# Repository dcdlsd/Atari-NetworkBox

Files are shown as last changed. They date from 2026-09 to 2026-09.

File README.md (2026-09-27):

# The Atari NetworkBox

> Français d'abord — English version below.

Une passerelle réseau autonome pour Atari ST : le port modem RS-232 est
converti par un MAX3232 vers un Raspberry Pi Pico 2 W. L'Atari utilise STinG
en SLIP à **19 200 bauds, 8N1** et peut accéder au réseau par Wi-Fi ou RJ45.

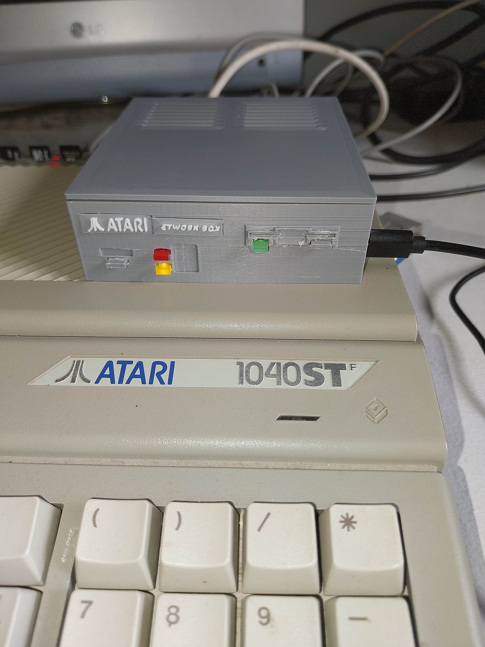
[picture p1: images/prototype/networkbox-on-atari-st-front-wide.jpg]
Prototype


## Fonctions validées

- navigation HTTP avec HighWire ;
- FTP avec Litchi ;
- DNS, ping et TCP/IP via STinG / SLIP ;
- firmware Wi-Fi seul, RJ45/W5500 seul, ou Wi-Fi + RJ45 unifié ;
- bouton de sélection et LEDs facultatives pour le firmware unifié.

## Vitesse série — important

Les **trois firmwares UF2 fournis** (Wi-Fi seul, RJ45 seul et unifié) sont
compilés avec une vitesse série **fixe de 19 200 bauds, 8N1**. Le port série
utilisé par STinG sur l'Atari doit être réglé à la même vitesse.

Ce réglage a été validé sur notre Atari STF. Il concerne la liaison série
Atari–Pico, pas la vitesse du Wi-Fi ou de l'Ethernet, et ne constitue pas une
limite matérielle du Pico.

Brancher la NetworkBox sur un autre modèle d'Atari ne change pas automatiquement
cette vitesse. Pour utiliser un port série plus rapide, il faudrait adapter
et recompiler le firmware, puis valider le fonctionnement sur la machine et
le port concernés. **Les vitesses supérieures ne sont pas validées dans cette
version.**

## Démarrage rapide

1. Imprimez le boîtier de `case_stl/` si souhaité, puis suivez le
   [montage en photos](docs/ASSEMBLY.md) pour placer le Pico et les modules.
2. Réalisez le câblage décrit dans [WIRING.md](WIRING.md).
3. Flashez **un seul** fichier `.uf2` depuis `firmware/` :
   - `...WIFI_only_v1.0.5.uf2` : Wi-Fi uniquement ;
   - `...W5500_RJ45_only_v1.0.4.uf2` : RJ45 uniquement ;
   - `...WIFI_and_RJ45_v0.6.5.uf2` : version unifiée recommandée.
4. Installez STinG sur l'Atari puis utilisez les exemples de
   `atari_config_examples/`. Consultez `docs/STING_SETUP.md`.
5. Pour le Wi-Fi, utilisez le portail de configuration décrit dans
   `docs/WIFI_SETUP.md`.

Les fichiers `.uf2` s'installent en maintenant **BOOTSEL** enfoncé pendant le
branchement USB du Pico, puis en déposant le fichier sur le disque USB du Pico.

## Organisation

- `firmware/` : firmwares compilés prêts à flasher ;
- `source/` : code source des trois variantes ;
- `case_stl/` : boîtier imprimable ;
- `atari_config_examples/` : exemples STinG et Litchi ;
- `images/` : prototype, schéma et captures Atari ;
- `docs/` : installation et ressources.

## État du prototype

Projet matériel open source réalisé comme prototype. Les modules, le boîtier
et les connecteurs peuvent varier : vérifiez toujours les sérigraphies de votre
MAX3232 et W5500 avant alimentation. Voir [WIRING.md](WIRING.md).

## Licence

Le code source et les firmwares sont sous [licence MIT](LICENSE). Le boîtier,
le câblage, les images et la documentation sont sous [CC BY
4.0](LICENSES/CC-BY-4.0.md). La réutilisation et la vente sont autorisées, à
condition de conserver le crédit de Denis Costils et les notices de licence.
Les composants tiers conservent leurs propres licences : voir
[THIRD_PARTY_NOTICES.md](THIRD_PARTY_NOTICES.md).

---

# English

The Atari NetworkBox is a standalone network gateway for the Atari ST. A
MAX3232 converts the RS-232 modem port to a Raspberry Pi Pico 2 W UART. The
Atari runs STinG over SLIP at **19,200 baud, 8N1**, with Wi-Fi or Ethernet
connectivity.

Validated features: HTTP with HighWire, FTP with Litchi, DNS, ping and TCP/IP.
Three ready-to-flash firmwares are supplied: Wi-Fi only, W5500 Ethernet only,
and a combined Wi-Fi + Ethernet version.

## Serial speed — important

All **three supplied UF2 firmwares** (Wi-Fi only, Ethernet only and combined)
are compiled for a **fixed serial speed of 19,200 baud, 8N1**. The Atari serial
port used by STinG must be configured to match.

This setting has been tested on our Atari STF. It applies to the Atari–Pico
serial link, not to Wi-Fi or Ethernet speed, and is not a hardware limitation
of the Pico.

Connecting the NetworkBox to another Atari model does not automatically change
the serial speed. Using a faster serial port would require adapting and
recompiling the firmware, then testing it on the relevant machine and port.
**Higher serial speeds have not been validated in this version.**

## Getting started

See the [photo assembly guide](docs/ASSEMBLY.md) for the Pico and module
positions, [WIRING.md](WIRING.md) for hardware connections,
`docs/STING_SETUP.md` for Atari configuration and `docs/WIFI_SETUP.md` for
Wi-Fi setup.

## License

Source code and firmware are [MIT licensed](LICENSE). Case files, wiring,
images and documentation are licensed under [CC BY 4.0](LICENSES/CC-BY-4.0.md).
Commercial reuse is allowed with credit and preservation of license notices.

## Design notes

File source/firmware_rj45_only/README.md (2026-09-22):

# NetworkBox SLIP / W5500 test

Separate Pico 2 W firmware for testing the Atari SLIP link through the W5500.
The validated Wi-Fi firmware remains in `../networkbox_slip_wifi` and is not
modified by this project.

## Wiring

- Atari RS-232 through MAX3232: Pico GP0 TX, GP1 RX, 19200 baud, 8N1.
- W5500 SPI0: MISO GP16, CS/SS GP17, SCK GP18, MOSI GP19, RESET GP20.
- Connect Ethernet to the same LAN/router that provides DHCP before powering
  the Pico. The firmware waits for physical link and then requests DHCP.

## Test

1. Flash `releases/networkbox_slip_w5500_ping_test.uf2` to the Pico 2 W.
2. Open the Pico USB serial monitor at 115200 baud.
3. Wait for `W5500 Ethernet link up`, then for `NetworkBox active - W5500 IP ...`.
4. Start STinG on the Atari and run the existing `PING.PRG` against the router
   (usually `192.168.1.254`) first. Once that works, try the PC IP.
5. Keep the Wi-Fi UF2 as the rollback option; this W5500 image has not yet been
   validated on the physical Network Box.

## Build

Open this directory as a separate Pico project in VS Code and build
`networkbox_slip_w5500`. It uses the local Pico SDK 2.3.1 and the WIZnet
ioLibrary_Driver plus WIZnet's lwIP MACRAW adapter. The adapter's SPI pins are
the same as the wiring listed above.

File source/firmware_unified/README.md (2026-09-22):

# NetworkBox unified test

This is an independent experimental project. The two validated projects
`networkbox_slip_wifi_setup` and `networkbox_slip_w5500` are not modified.

## Behaviour of v0.1

- If the RJ45 cable is connected when Pico starts, the W5500 is selected.
- Otherwise, Pico connects with the saved Wi-Fi configuration.
- If Wi-Fi credentials are missing or invalid, the existing setup page starts:
  `NetworkBox-Setup`, password `networkbox`, page `http://192.168.4.1`.
- There is deliberately no button or LED support in this first unified test.

The temporary access point is WPA2 protected. The saved password is not shown
by the page or in USB logs.

## Hardware test

1. Keep the validated Wi-Fi and W5500 UF2 files as backups.
2. Copy `releases/networkbox_unified_v0.1_boot_rj45_wifi_fallback.uf2` to Pico 2 W
   in BOOTSEL mode.
3. First test with RJ45 connected: the monitor must show `W5500 set as default`
   and then `NetworkBox active - W5500 OK`.
4. Validate Atari ping, then HighWire or FTP.
5. Reflash only if needed, unplug RJ45, and boot again. The monitor must show
   `Connecting to saved Wi-Fi...` followed by `NetworkBox active - Wi-Fi OK`.
6. Validate Atari ping, then HighWire or FTP again.

## Current scope

This test deliberately has no button, LEDs, live cable failover, or factory
reset. Those belong in the next unified firmware step.

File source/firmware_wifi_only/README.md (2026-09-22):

# Atari NetworkBox — firmware Wi-Fi seul

Firmware pour Raspberry Pi Pico 2 W. Il relie un Atari ST configure avec
STinG/SLIP a un reseau Wi-Fi via le montage RS-232 et MAX3232.

Cette edition est independante du W5500 : aucun module Ethernet, bouton ou
LED n'est requis.

## Premier demarrage

1. Flasher le fichier `.uf2` sur le Pico 2 W.
2. Depuis un telephone ou un PC, rejoindre le Wi-Fi `NetworkBox-Setup` avec le
   mot de passe `networkbox`.
3. Ouvrir `http://192.168.4.1`.
4. Choisir le Wi-Fi dans la liste (ou saisir un SSID masque), entrer le mot de
   passe puis enregistrer.
5. Le Pico redemarre et memorise les identifiants dans sa propre memoire flash.

Les identifiants ne sont pas inclus dans les sources ni dans le fichier UF2.

## Changer de reseau plus tard

Le bouton est facultatif. S'il est installe entre **GP4** et **GND**, un appui
maintenu trois secondes pendant que le Wi-Fi est connecte reouvre le portail
de configuration. Sans bouton, le portail s'ouvre automatiquement si le
reseau memorise ne peut plus etre rejoint.

## Atari ST

Configurer STinG en SLIP sur le port modem, a **19 200 bauds, 8N1** :

- Atari : `192.168.7.2`
- passerelle : `192.168.7.1`
- masque : `255.255.255.0`

La configuration a ete validee avec ping, DNS, HTTP/HighWire et FTP/Litchi.

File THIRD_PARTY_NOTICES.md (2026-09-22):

# Third-party notices

The project source tree contains third-party components. Their original
license notices are retained beside the relevant source files and take
precedence for those components.

In particular, the WIZnet ioLibrary Driver is distributed with its original
license text in each firmware source folder as `LICENSE-ioLibrary.txt`.

Raspberry Pi Pico SDK and lwIP components are obtained through the normal Pico
SDK build process and remain under their respective upstream licenses.

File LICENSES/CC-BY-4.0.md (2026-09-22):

# CC BY 4.0 — hardware, case and documentation

Copyright (c) 2026 Denis Costils

Unless a file says otherwise, the following parts of The Atari NetworkBox are
licensed under the [Creative Commons Attribution 4.0 International
license](https://creativecommons.org/licenses/by/4.0/):

- `case_stl/`
- `images/`
- `WIRING.md`
- `docs/`
- `atari_config_examples/`

You may share and adapt these materials for any purpose, including commercial
use, provided that you give appropriate credit to **Denis Costils**, link to
the license, and state whether changes were made.

The complete legal text is available at
https://creativecommons.org/licenses/by/4.0/legalcode.

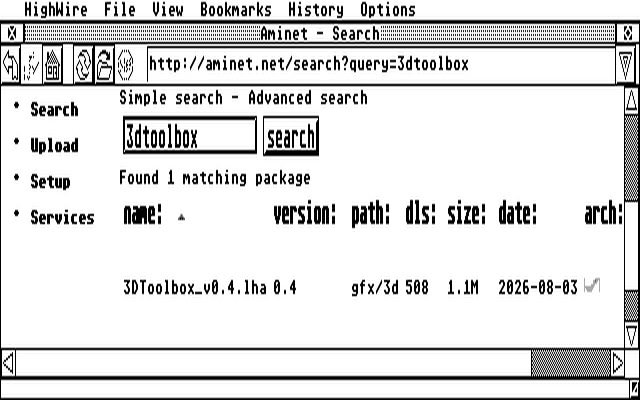
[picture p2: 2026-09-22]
images/atari-screenshots/highwire-aminet-search.jpg

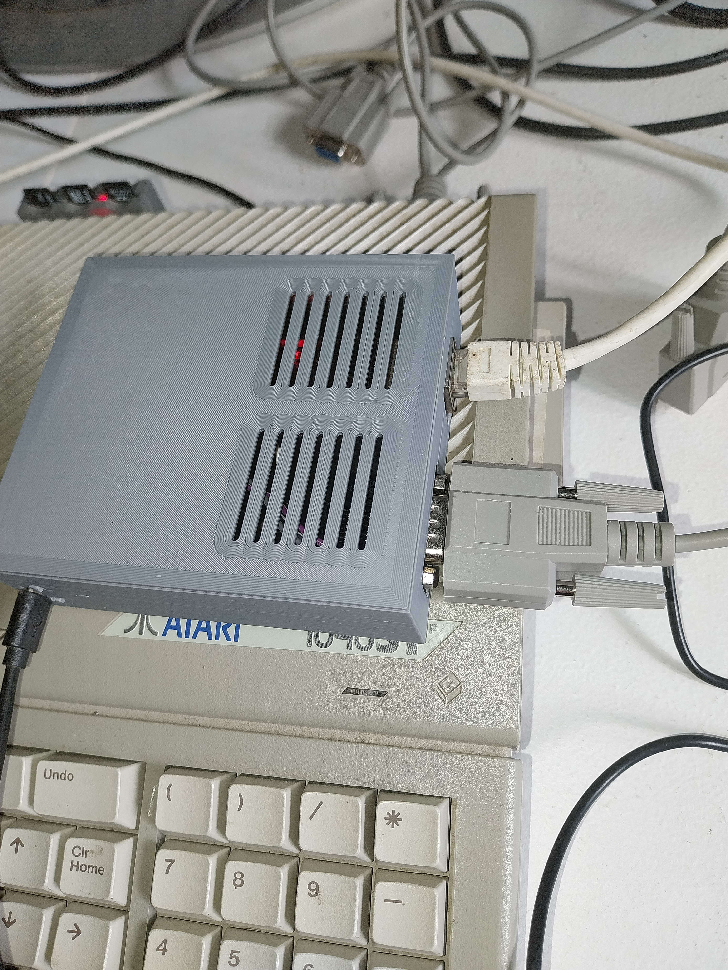
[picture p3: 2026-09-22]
images/prototype/networkbox-top-db9-and-rj45.jpg

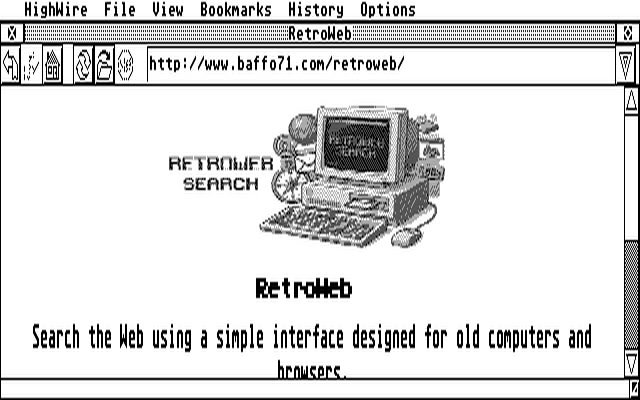
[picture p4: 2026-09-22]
images/atari-screenshots/highwire-retroweb.jpg

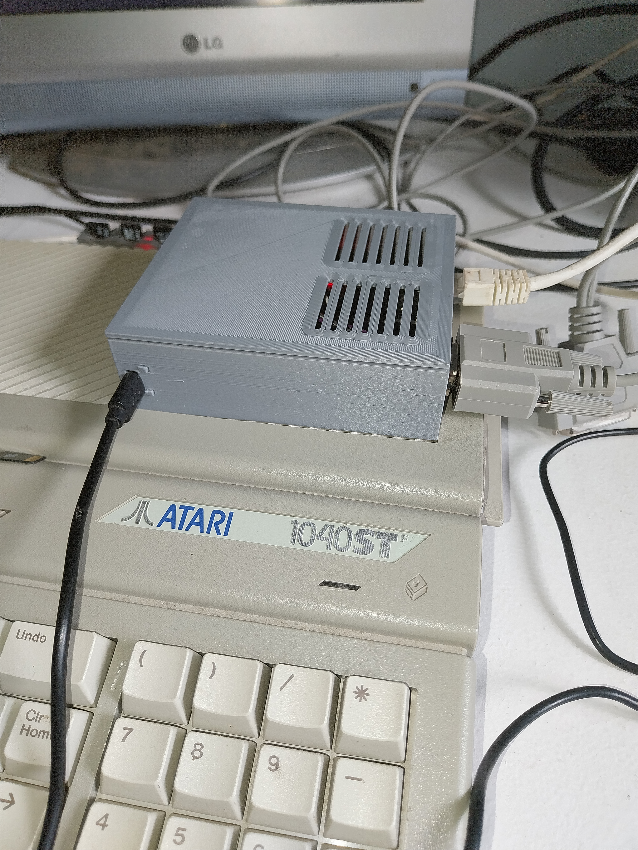
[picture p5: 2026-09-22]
images/prototype/networkbox-top-and-rj45.jpg

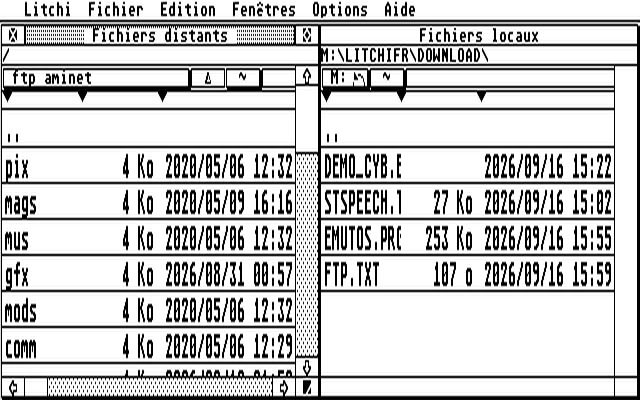
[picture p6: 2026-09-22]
images/atari-screenshots/litchi-ftp-file-transfer.jpg

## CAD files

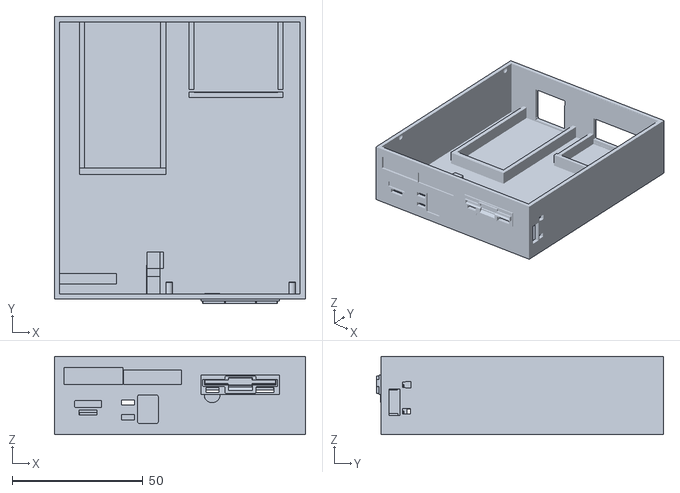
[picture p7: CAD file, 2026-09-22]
case_stl/atari_networkbox_bottom.stl
95.9 x 109.7 x 30.0

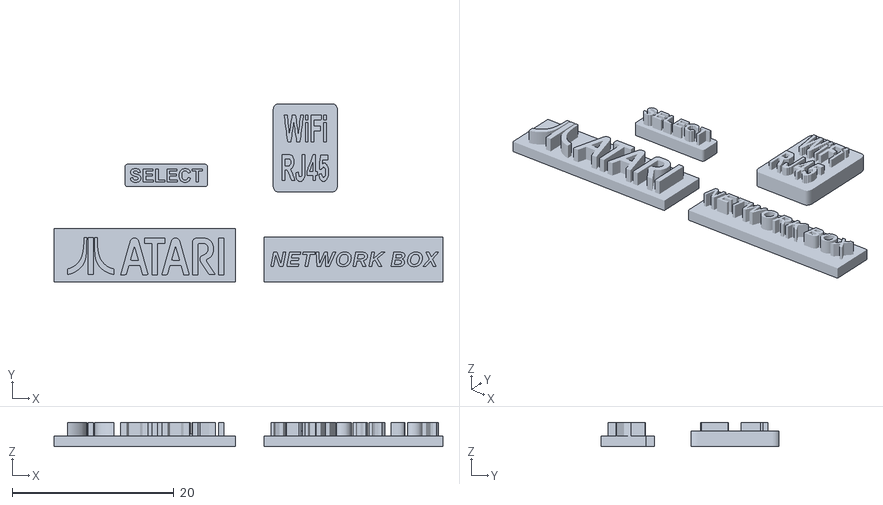
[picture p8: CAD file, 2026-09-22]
case_stl/atari_logo.stl
48.1 x 22.0 x 3.00

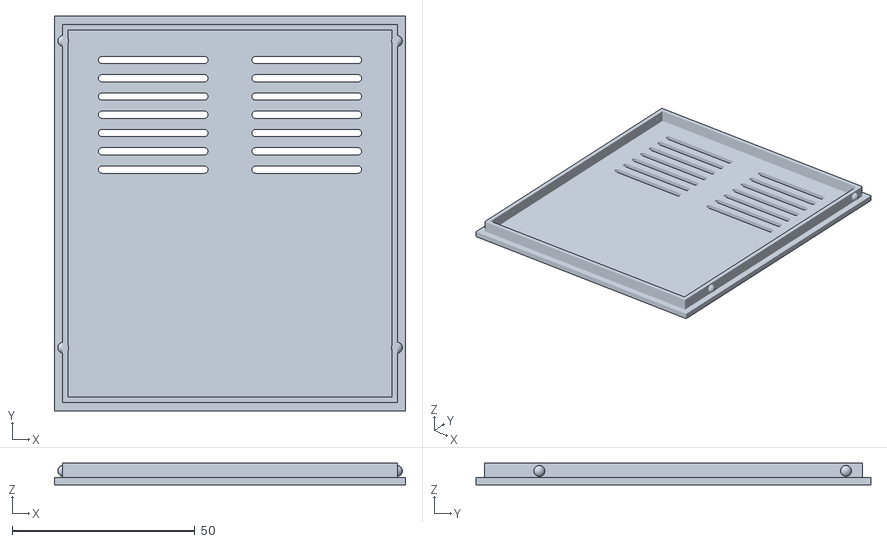
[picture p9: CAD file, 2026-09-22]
case_stl/atari_networkbox_top.stl
96.0 x 108.0 x 6.00

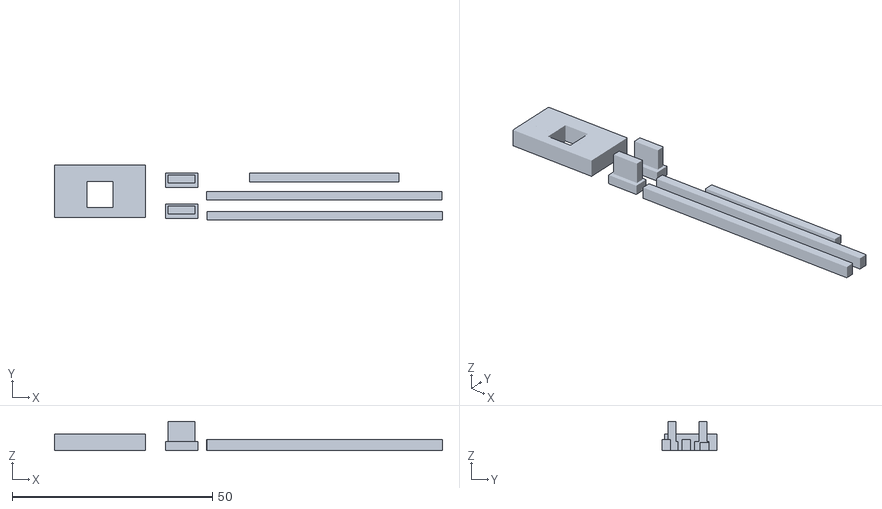
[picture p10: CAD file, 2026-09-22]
case_stl/accessory.stl
97.0 x 13.8 x 7.35

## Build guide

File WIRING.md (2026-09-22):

# Atari NetworkBox — schéma de câblage

**Français : première partie de ce document. English: full translation in the
second part of this document.**

Ce schéma correspond au firmware **Wi-Fi + RJ45 unifié** pour Raspberry Pi
Pico 2 W. Toutes les masses (`GND`) doivent être communes.

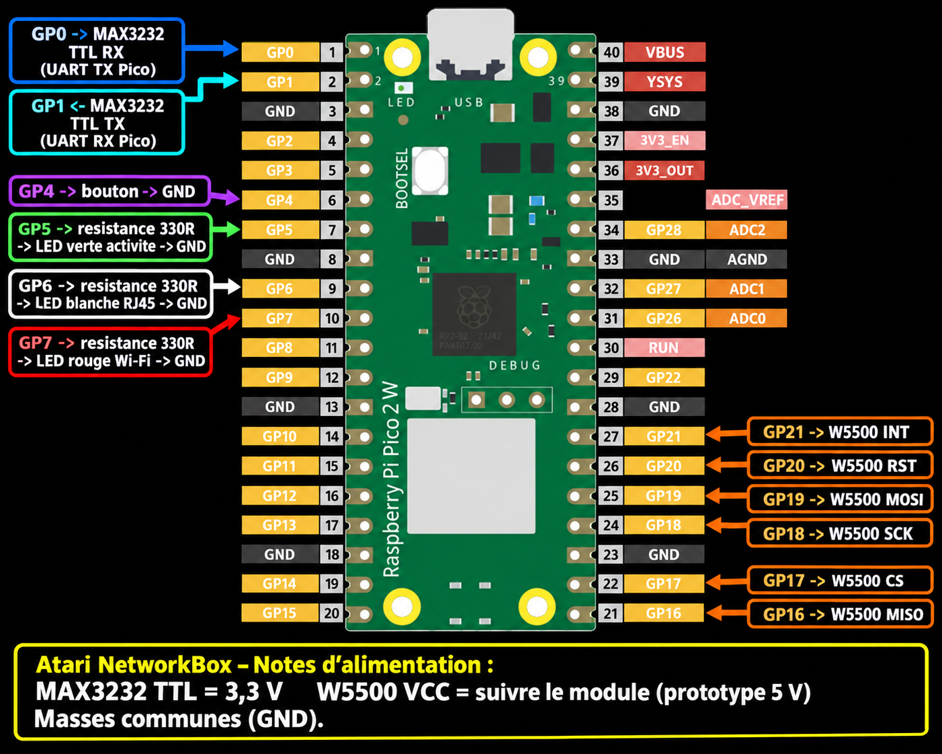
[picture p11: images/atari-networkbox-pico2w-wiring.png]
Plan des GPIO du Pico 2 W


> Important : le Pico est en logique **3,3 V**. La partie TTL du MAX3232 doit
> être en 3,3 V. Les signaux GPIO du Pico ne doivent jamais recevoir 5 V.

```mermaid
flowchart LR
  ST[Atari ST\nPort modem RS-232] <-->|RS-232| MAX[MAX3232]
  MAX <-->|UART TTL 3,3 V| PICO[Raspberry Pi Pico 2 W]
  PICO <-->|SPI 3,3 V| W5500[Module W5500\nRJ45]
  BTN[Bouton] --- PICO
  LED[LEDs optionnelles] --- PICO
```

## 1. Atari ST vers MAX3232

Sur le port modem DB25 de l'Atari :

| Atari ST | Rôle | MAX3232 côté RS-232 |
|---|---|---|
| DB25 broche 2 | TXD, sortie Atari | RXD, entrée du MAX3232 |
| DB25 broche 3 | RXD, entrée Atari | TXD, sortie du MAX3232 |
| DB25 broche 7 | masse signal | GND |

Si le boîtier utilise une DB9 et un adaptateur/null-modem DB9 ↔ DB25, le
principe ne change pas : **TX de l'Atari arrive sur RX du MAX3232, et inversement**.

## 2. MAX3232 vers Pico 2 W

| Pico 2 W | Signal | MAX3232 côté TTL |
|---|---|---|
| GP0 | UART0 TX, sortie Pico | RXD / entrée TTL du module |
| GP1 | UART0 RX, entrée Pico | TXD / sortie TTL du module |
| 3V3(OUT) | alimentation logique | VCC |
| GND | masse | GND |

Les sérigraphies `TXD` et `RXD` varient selon les petits modules MAX3232.
La règle à suivre est toujours : **TX Pico → RX module** et **TX module → RX Pico**.

Réglage série Atari : **19 200 bauds, 8N1, SLIP**.

## 3. Pico 2 W vers W5500

| Pico 2 W | W5500 | Fonction |
|---|---|---|
| GP16 | MISO | données W5500 → Pico |
| GP17 | CS / SCS | sélection du W5500 |
| GP18 | SCK / SCLK | horloge SPI |
| GP19 | MOSI | données Pico → W5500 |
| GP20 | RST / RESET | réinitialisation W5500 |
| GP21 | INT | interruption W5500 |
| 5V (VBUS) ou 3V3(OUT), selon le module | VCC | alimentation du module |
| GND | GND | masse |

Le **W5500 nu fonctionne en 3,3 V**, mais beaucoup de modules W5500 vendus
pour Arduino/Raspberry possèdent un régulateur et acceptent aussi le **5 V**
sur leur broche `VCC`. C'est le cas du module utilisé pour ce prototype : il
est alimenté en **5 V**. Il faut donc suivre la sérigraphie ou la fiche du
module exact. Quel que soit son VCC, les lignes SPI venant du Pico restent en
logique **3,3 V**.

## 4. Bouton et LEDs — firmware unifié

Le bouton et les LEDs sont facultatifs pour le firmware Wi-Fi seul. Ils sont
utilisés par le firmware unifié.

### Bouton

| Pico 2 W | Câblage |
|---|---|
| GP4 | une patte du bouton |
| GND | autre patte du bouton |

Le firmware utilise une résistance interne : **aucune résistance externe n'est
nécessaire**. Au démarrage, maintenir le bouton force le Wi-Fi. Une fois en
Wi-Fi, maintenir trois secondes ouvre la page de configuration.

### LEDs

Chaque LED utilise une résistance en série de **330 Ω à 1 kΩ**. Une résistance
de 330 Ω fonctionne, mais 680 Ω ou 1 kΩ donne une lumière moins agressive.

| Pico 2 W | Couleur proposée | Fonction |
|---|---|---|
| GP5 → résistance → anode LED, cathode → GND | verte | activité réseau |
| GP6 → résistance → anode LED, cathode → GND | blanche | RJ45 sélectionné |
| GP7 → résistance → anode LED, cathode → GND | rouge | Wi-Fi sélectionné ; clignote pendant la configuration |

## Vérification avant mise sous tension

1. Vérifier une masse commune Pico, MAX3232 et W5500.
2. Alimenter le MAX3232 en 3,3 V ; pour le W5500, suivre la tension indiquée
   par le module (5 V pour le module du prototype).
3. Vérifier le croisement TX/RX entre Pico et MAX3232.
4. Ne pas relier directement une sortie RS-232 de l'Atari au Pico : le
   MAX3232 est obligatoire pour convertir les niveaux électriques.

## Limitation connue du prototype RJ45

Si le réseau RJ45 devient totalement inactif et que la LED d'activité reste
fixe, débrancher puis rebrancher l'alimentation de la NetworkBox afin de
réinitialiser le Pico et le W5500. La récupération automatique du W5500 est
prévue pour une évolution ultérieure.

---

# English version

This wiring guide is for the **Wi-Fi + RJ45 unified firmware** running on a
Raspberry Pi Pico 2 W. All grounds (`GND`) must be connected together.

> Important: the Pico GPIO logic level is **3.3 V**. The MAX3232 TTL side must
> use 3.3 V. Never connect 5 V directly to a Pico GPIO pin.

## 1. Atari ST to MAX3232

| Atari ST DB25 modem port | Role | MAX3232 RS-232 side |
|---|---|---|
| Pin 2 | TXD, Atari output | RXD, MAX3232 input |
| Pin 3 | RXD, Atari input | TXD, MAX3232 output |
| Pin 7 | signal ground | GND |

With a DB9 ↔ DB25 adapter/null-modem cable, the rule is unchanged: **Atari TX
goes to MAX3232 RX, and vice versa**.

## 2. MAX3232 to Pico 2 W

| Pico 2 W | Signal | MAX3232 TTL side |
|---|---|---|
| GP0 | UART0 TX, Pico output | RXD / TTL input of the module |
| GP1 | UART0 RX, Pico input | TXD / TTL output of the module |
| 3V3(OUT) | logic supply | VCC |
| GND | ground | GND |

The `TXD` and `RXD` labels differ between MAX3232 modules. Always follow the
signal direction: **Pico TX → module RX** and **module TX → Pico RX**.

Atari serial settings: **19,200 baud, 8N1, SLIP**.

## 3. Pico 2 W to W5500

| Pico 2 W | W5500 | Function |
|---|---|---|
| GP16 | MISO | W5500 → Pico data |
| GP17 | CS / SCS | W5500 chip select |
| GP18 | SCK / SCLK | SPI clock |
| GP19 | MOSI | Pico → W5500 data |
| GP20 | RST / RESET | W5500 reset |
| GP21 | INT | W5500 interrupt |
| 5V (VBUS) or 3V3(OUT), depending on module | VCC | module supply |
| GND | GND | ground |

The bare W5500 chip runs at 3.3 V. Many W5500 modules include a regulator and
accept 5 V on `VCC`. The prototype module is powered with **5 V**. Follow the
markings or datasheet of the exact module; Pico SPI signals always remain at
**3.3 V**.

## 4. Button and LEDs — unified firmware

The button and LEDs are optional with the Wi-Fi-only firmware, but used by the
unified firmware.

### Button

| Pico 2 W | Wiring |
|---|---|
| GP4 | one button leg |
| GND | other button leg |

An internal pull-up is used: **no external resistor is required**. Holding the
button at boot forces Wi-Fi. Once in Wi-Fi mode, hold it for three seconds to
open the configuration page.

### LEDs

Use one **330 Ω to 1 kΩ** series resistor per LED. 330 Ω works but 680 Ω or
1 kΩ gives a softer light.

| Pico 2 W | Suggested colour | Function |
|---|---|---|
| GP5 → resistor → LED anode, cathode → GND | green | network activity |
| GP6 → resistor → LED anode, cathode → GND | white | RJ45 selected |
| GP7 → resistor → LED anode, cathode → GND | red | Wi-Fi selected; blinks during setup |

## Check before powering on

1. Check the common ground between Pico, MAX3232 and W5500.
2. Supply the MAX3232 at 3.3 V. For the W5500, use the voltage stated by the
   module (5 V for the prototype module).
3. Check that TX/RX are crossed between Pico and MAX3232.
4. Never connect Atari RS-232 directly to the Pico: the MAX3232 level shifter
   is mandatory.

## Known RJ45 prototype limitation

If the RJ45 connection becomes completely inactive and the activity LED stays
on continuously, unplug and reconnect NetworkBox power to reset the Pico and
W5500. Automatic W5500 recovery is planned for a later revision.

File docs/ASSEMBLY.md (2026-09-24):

# Montage du boîtier / Case assembly

## Français

Ces photos montrent **le prototype réellement monté**. Commencez par repérer
les logements imprimés avant de brancher les fils. Pour les connexions
électriques, utilisez les **numéros de broches dans
[WIRING.md](../WIRING.md)** : la couleur des fils Dupont n'indique pas leur
fonction.

### 1. Placer le Pico, puis ses rails de maintien

Les deux longues pièces imprimées sont des rails amovibles : elles se glissent
**derrière le Raspberry Pi Pico 2 W** pour le maintenir. La photo ci-dessous
montre leur emplacement dans le boîtier vide.

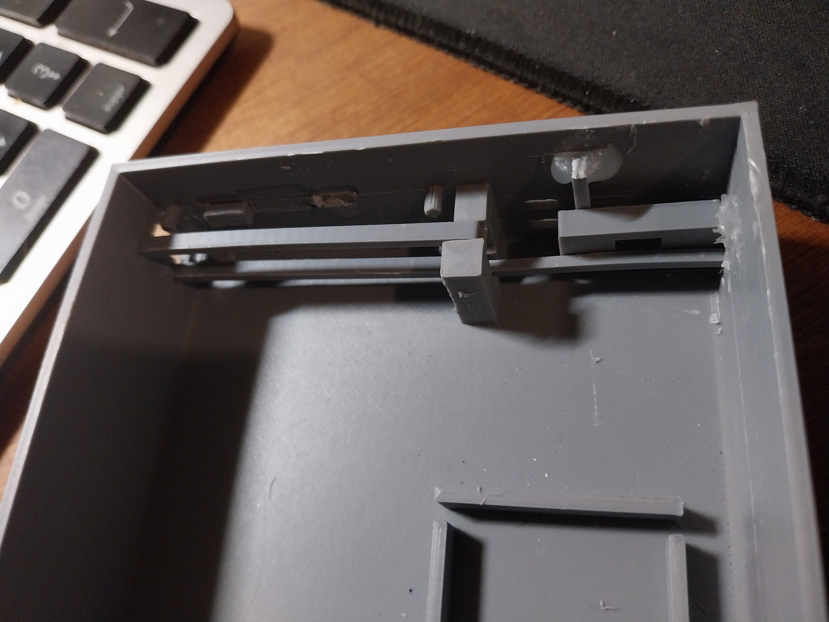
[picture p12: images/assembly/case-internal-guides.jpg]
Glissières vues dans le boîtier vide


Cette vue rapprochée montre les rails avant leur mise en place.

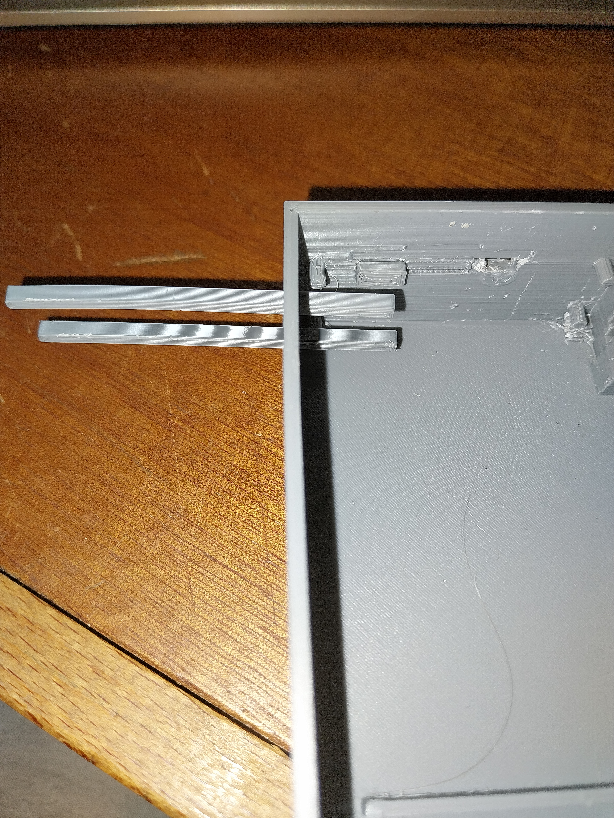
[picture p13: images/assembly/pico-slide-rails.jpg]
Extrémité des glissières du Pico


Les vues 3D suivantes précisent le montage : Pico en jaune, rails en vert et
boîtier transparent en bleu. Les flèches colorées sont les poignées de
déplacement de 3D Builder, **pas** des indications du sens de montage.

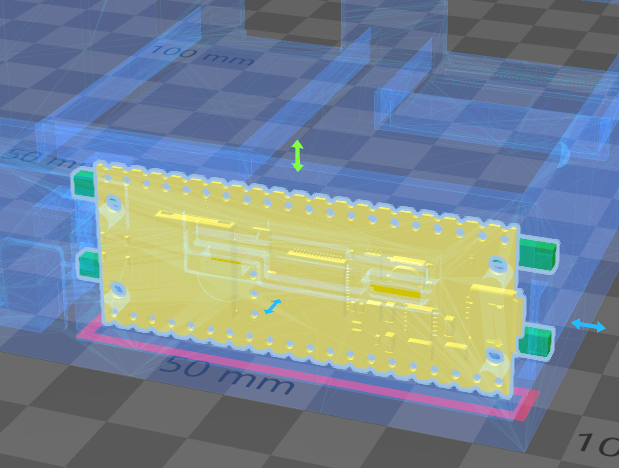
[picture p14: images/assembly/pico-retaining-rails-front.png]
Position du Pico et des rails, vue de face


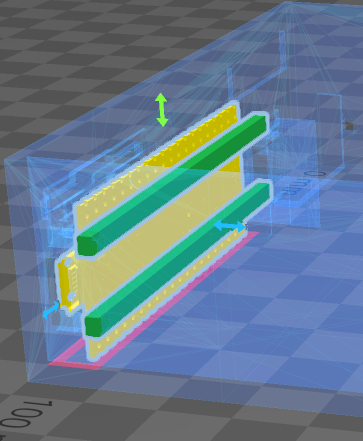
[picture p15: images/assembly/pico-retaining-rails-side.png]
Position du Pico et des rails, vue de côté


Positionnez **d'abord le Pico** dans son logement, avec son connecteur USB
orienté vers la découpe du boîtier. Faites **ensuite coulisser les deux rails
derrière la carte** pour la retenir. Vérifiez la position, la tenue et l'accès
USB **avant** d'enfoncer les connecteurs Dupont ; ne forcez pas si une carte
ou un fil touche une paroi.

### 2. Placer les autres modules

Sur ce prototype, le module MAX3232 avec son connecteur DB9 est à gauche et
le module W5500 avec sa prise RJ45 est à droite, vus depuis l'intérieur et
avec les prises orientées vers l'extérieur.

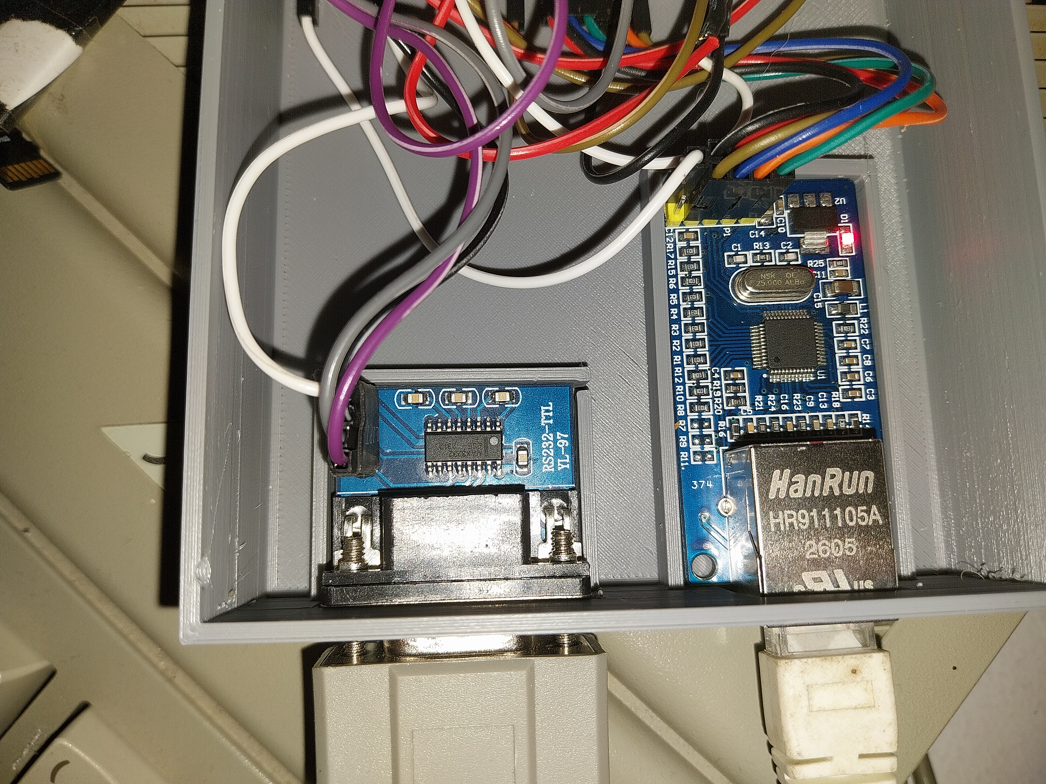
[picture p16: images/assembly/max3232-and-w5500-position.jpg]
MAX3232 à gauche et W5500 à droite


La vue ci-dessous montre le Pico en place et le passage réel des fils. Elle
aide à visualiser l'encombrement, mais **ne remplace pas le schéma de
câblage** : les étiquettes des broches sont cachées par les fils sur la photo.

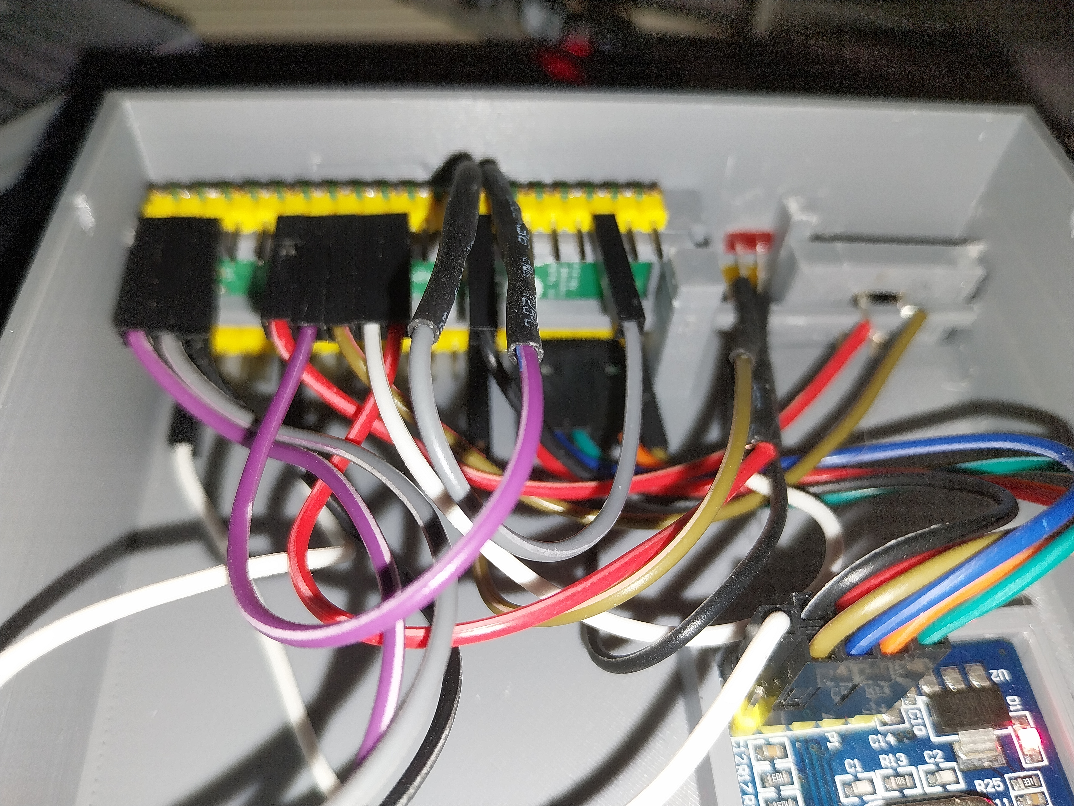
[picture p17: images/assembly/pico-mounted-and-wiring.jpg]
Pico monté et fils Dupont


### 3. Vérifier le bouton avant de fermer

Le détail ci-dessous montre la pièce imprimée du bouton sur ce prototype.
Actionnez-la une fois à la main et vérifiez qu'elle revient librement avant
de poser le couvercle.

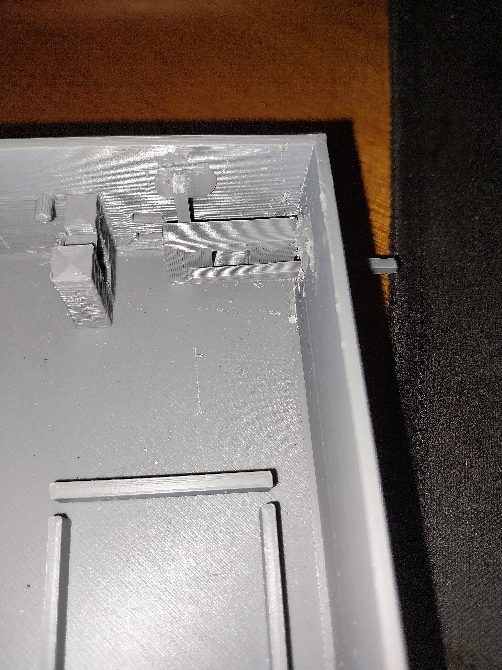
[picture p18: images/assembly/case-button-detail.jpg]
Détail du mécanisme du bouton


Après montage, contrôlez une dernière fois l'alimentation du MAX3232 en
3,3 V et celle de **votre modèle précis** de W5500. Le module W5500 de ce
prototype accepte le 5 V sur VCC ; d'autres modules peuvent différer. Les
signaux GPIO/SPI du Pico restent en 3,3 V.

---

## English

These photos show the actual prototype. Place the Raspberry Pi Pico 2 W in
its recess **first**, with its USB connector facing the case opening. Then
**slide the two removable rails behind the Pico** to hold it in place. The 3D
views above show the Pico in yellow, the rails in green and the transparent
case in blue. The coloured arrows are 3D Builder editing handles, **not**
assembly directions. Check the fit and USB access before attaching the Dupont
wires; do not force any part into place.

In the assembled prototype, the MAX3232/DB9 module is on the left and the
W5500/RJ45 module on the right when viewed from inside with the sockets facing
outward. The close-up of the fitted Pico shows available space and cable
routing. It does **not** identify GPIO connections: use the pin numbers in
[WIRING.md](../WIRING.md), not wire colours.

Check that the button moves freely before fitting the lid. Verify the power
requirements of your exact W5500 board; this prototype's module accepts 5 V
on VCC, while Pico GPIO and SPI signals are always 3.3 V.

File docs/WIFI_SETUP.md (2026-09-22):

# Configuration Wi-Fi

## Français

Les identifiants Wi-Fi ne sont pas compilés dans les firmwares distribués.

1. Flashez un firmware contenant le Wi-Fi.
2. S'il n'a pas encore d'identifiants enregistrés, le Pico crée le réseau
   Wi-Fi `NetworkBox-Setup`.
3. Connectez un téléphone ou un PC à ce réseau avec le mot de passe
   `networkbox`.
4. Ouvrez `http://192.168.4.1` dans le navigateur.
5. Sélectionnez votre réseau, entrez son mot de passe puis sauvegardez.
6. La NetworkBox redémarre et rejoint votre Wi-Fi. Les identifiants sont
   mémorisés dans le Pico.

Sur le firmware unifié, le bouton est relié entre GP4 et GND. Un appui long
d'environ trois secondes, lorsque le Wi-Fi est sélectionné, ouvre à nouveau
le portail de configuration.

## English

No Wi-Fi credentials are compiled into release firmware. On first start, join
the `NetworkBox-Setup` access point (password: `networkbox`) and open
`http://192.168.4.1`. Select your network, enter its password and save. The
Pico restarts and stores the credentials.

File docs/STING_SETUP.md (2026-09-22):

# Configuration STinG / SLIP

## Français

L'Atari STF d'origine doit utiliser **19 200 bauds, 8N1**. Le MFP d'origine
ne génère pas correctement 38 400 bauds.

1. Installez STinG 1.26 et HSMODEM sur le disque Atari.
2. Copiez `atari_config_examples/DEFAULT.CFG.example` dans le dossier de
   STinG sous le nom `DEFAULT.CFG`.
3. Dans STinG Port Setup, configurez le port série avec :
   - pilote SLIP / SERIAL.STX ;
   - 19 200 bauds, 8N1 ;
   - Atari : `192.168.7.2` ;
   - passerelle Pico : `192.168.7.1` ;
   - masque : `255.255.255.0` ;
   - DNS : l'adresse de votre routeur (par exemple `192.168.1.254`).
4. Redémarrez l'Atari après toute modification STinG.
5. Testez d'abord un ping vers `192.168.7.1`, puis vers votre routeur.

Le fichier exemple utilise `MSS = 536`, `RCV_WND = 2144` et `DEF_RTT = 1500` :
des valeurs adaptées à une liaison série à 19 200 bauds.

### Mise à jour TCP.STX 1.40 (facultative)

TCP.STX 1.40 corrige notamment des problèmes de fermeture TCP et de dernier
paquet FTP/HTTP. Sauvegardez l'ancien `TCP.STX` avant de le remplacer, puis
redémarrez l'Atari.

## English

Use SLIP at **19,200 baud, 8N1**. Configure the Atari as `192.168.7.2`, Pico
gateway as `192.168.7.1`, netmask `255.255.255.0`, and DNS as your router IP.
Reboot the Atari after changes. Test the Pico gateway first, then the router.

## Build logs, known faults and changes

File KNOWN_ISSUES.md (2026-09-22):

# Notes et limites connues

- Un Atari STF standard est limité à **19 200 bauds** sur son port modem.
  Les téléchargements FTP volumineux sont donc volontairement lents.
- Les modules W5500 ne sont pas tous identiques. Vérifiez si votre modèle
  accepte 5 V sur `VCC`; les signaux SPI du Pico restent toujours en 3,3 V.
- Le firmware RJ45 surveille le W5500 et tente une récupération automatique
  en cas de transmission bloquée. Si le module ne revient pas après cela,
  coupez puis remettez l'alimentation de la NetworkBox.
- Les fichiers `*.example` contiennent des chemins et une adresse DNS à
  adapter à votre installation Atari et votre routeur.

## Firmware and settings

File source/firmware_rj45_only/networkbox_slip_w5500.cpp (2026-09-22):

#include <stdio.h>
#include "pico/stdlib.h"
#include "hardware/uart.h"
#include "hardware/irq.h"
#include "hardware/sync.h"
#include "hardware/clocks.h"
#include "hardware/watchdog.h"
extern "C" {
#include "wizchip_conf.h"
#include "socket.h"
#include "w5x00_spi.h"
#include "w5x00_lwip.h"
}
#include <string.h>
#include "lwip/init.h"
#include "lwip/ip.h"
#include "lwip/netif.h"
#include "lwip/pbuf.h"
#include "lwip/etharp.h"
#include "lwip/dhcp.h"
#include "lwip/timeouts.h"

extern "C" uint8_t mac[6];


// UART defines
// By default the stdout UART is `uart0`, so we will use the second one
#define UART_ID uart0
#define BAUD_RATE 19200

// Use pins 4 and 5 for UART1
// Pins can be changed, see the GPIO function select table in the datasheet for information on GPIO assignments
#define UART_TX_PIN 0
#define UART_RX_PIN 1

// Optional front-panel LEDs used by the NetworkBox enclosure.
#define LED_ACTIVITY_PIN 5
#define LED_ETHERNET_PIN 6
#define LED_WIFI_PIN 7

static constexpr uint8_t SLIP_END = 0xC0;
static constexpr uint8_t SLIP_ESC = 0xDB;
static constexpr uint8_t SLIP_ESC_END = 0xDC;
static constexpr uint8_t SLIP_ESC_ESC = 0xDD;
static constexpr size_t SLIP_MAX_FRAME = 1600;
// UART ISR buffers incoming bytes while lwIP/Wi-Fi callbacks are busy.
static constexpr uint32_t UART_RX_RING_SIZE = 4096;
static constexpr uint32_t UART_RX_RING_MASK = UART_RX_RING_SIZE - 1;
static_assert((UART_RX_RING_SIZE & UART_RX_RING_MASK) == 0,
              "UART RX ring size must be a power of two");
static uint8_t uart_rx_ring[UART_RX_RING_SIZE];
static volatile uint32_t uart_rx_head = 0;
static volatile uint32_t uart_rx_tail = 0;
static volatile uint32_t uart_rx_overflow = 0;

static uint8_t slip_frame[SLIP_MAX_FRAME];
static size_t slip_length = 0;
static bool slip_in_frame = false;
static bool slip_escaped = false;
static struct netif slip_netif;
static struct netif ethernet_netif;
static netif_output_fn original_ethernet_output = nullptr;
static netif_input_fn original_ethernet_input = nullptr;
static uint8_t ethernet_rx_frame[ETHERNET_MTU + 64];
static bool nat_icmp_active = false;
static uint8_t nat_icmp_client_ip[4] = {0};
static uint16_t nat_icmp_id = 0;
static uint16_t nat_icmp_sequence = 0;
static bool nat_dns_active = false;
static uint8_t nat_dns_client_ip[4] = {0};
static uint8_t nat_dns_server_ip[4] = {0};
static uint16_t nat_dns_client_port = 0;
static uint16_t nat_dns_transaction_id = 0;
// FTP clients such as Litchi briefly keep several control and data channels
// alive at once. Eight entries were too few during a transfer.
static constexpr size_t NAT_TCP_FLOW_COUNT = 16;
struct NatTcpFlow {
    bool active;
    bool client_fin_seen;
    bool server_fin_seen;
    bool reset_seen;
    uint8_t client_ip[4];
    uint8_t server_ip[4];
    uint16_t client_port;
    uint16_t server_port;
    uint32_t last_activity;
    uint32_t closed_at;
};
static NatTcpFlow nat_tcp_flows[NAT_TCP_FLOW_COUNT] = {};
static uint32_t activity_led_until_ms = 0;
static uint16_t checksum16(const uint8_t *data, size_t length);
static void slip_send_frame(const uint8_t *data, size_t length);

static void init_status_leds() {
    const uint8_t led_pins[] = {LED_ACTIVITY_PIN, LED_ETHERNET_PIN, LED_WIFI_PIN};
    for (uint8_t pin : led_pins) {
        gpio_init(pin);
        gpio_set_dir(pin, GPIO_OUT);
        gpio_put(pin, 0);
    }
}

static void mark_network_activity() {
    gpio_put(LED_ACTIVITY_PIN, 1);
    activity_led_until_ms = to_ms_since_boot(get_absolute_time()) + 80;
}

static void update_status_leds(uint32_t now) {
    gpio_put(LED_ETHERNET_PIN, 1); // This firmware is RJ45 only.
    gpio_put(LED_WIFI_PIN, 0);
    if (activity_led_until_ms && now >= activity_led_until_ms) {
        gpio_put(LED_ACTIVITY_PIN, 0);
        activity_led_until_ms = 0;
    }
}

static void uart_rx_irq_handler() {
    while (uart_is_readable(UART_ID)) {
        uint8_t byte = (uint8_t)uart_getc(UART_ID);
        uint32_t head = uart_rx_head;
        uint32_t next = (head + 1) & UART_RX_RING_MASK;
        if (next == uart_rx_tail) {
            ++uart_rx_overflow;
            continue;
        }
        uart_rx_ring[head] = byte;
        __dmb();
        uart_rx_head = next;
    }
}

static bool tcp_flow_expired(NatTcpFlow &flow, uint32_t now) {
    if (!flow.active) return true;
    if (flow.closed_at && now - flow.closed_at >= 2000) return true;
    if ((flow.client_fin_seen || flow.server_fin_seen) &&
        now - flow.last_activity >= 15000) return true;
    return now - flow.last_activity >= 120000;
}

static void update_tcp_flow(NatTcpFlow *flow, uint8_t flags,
                            bool from_client, uint32_t now) {
    if (!flow) return;
    flow->last_activity = now;
    if (flags & 0x04) { // RST
        flow->reset_seen = true;
        flow->closed_at = now;
    }
    if (flags & 0x01) { // FIN
        if (from_client) flow->client_fin_seen = true;
        else flow->server_fin_seen = true;
        if (flow->client_fin_seen && flow->server_fin_seen && !flow->closed_at)
            flow->closed_at = now;
    }
}

static void recalc_icmp_checksums(uint8_t *packet, size_t length) {
    if (length < 28 || (packet[0] >> 4) != 4) return;
    size_t ihl = (packet[0] & 0x0f) * 4;
    if (ihl < 20 || length < ihl + 8) return;
    packet[10] = packet[11] = 0;
    uint16_t ip_sum = checksum16(packet, ihl);
    packet[10] = (uint8_t)(ip_sum >> 8);
    packet[11] = (uint8_t)ip_sum;
    packet[ihl + 2] = packet[ihl + 3] = 0;
    uint16_t icmp_sum = checksum16(packet + ihl, length - ihl);
    packet[ihl + 2] = (uint8_t)(icmp_sum >> 8);
    packet[ihl + 3] = (uint8_t)icmp_sum;
}

static void recalc_udp_checksum(uint8_t *packet, size_t ip_length) {
    size_t ihl = (packet[0] & 0x0f) * 4;
    if (ihl < 20 || ip_length < ihl + 8 || packet[9] != 17) return;
    size_t udp_length = ((size_t)packet[ihl + 4] << 8) | packet[ihl + 5];
    if (udp_length < 8 || udp_length > ip_length - ihl) return;

    packet[ihl + 6] = packet[ihl + 7] = 0;
    uint32_t sum = 0;
    auto add_words = [&sum](const uint8_t *data, size_t length) {
        while (length > 1) {
            sum += ((uint16_t)data[0] << 8) | data[1];
            data += 2;
            length -= 2;
        }
        if (length) sum += (uint16_t)data[0] << 8;
    };
    add_words(packet + 12, 8); // IPv4 source + destination
    sum += 17;                 // zero byte + protocol number
    sum += (uint16_t)udp_length;
    add_words(packet + ihl, udp_length);
    while (sum >> 16) sum = (sum & 0xffff) + (sum >> 16);
    uint16_t result = (uint16_t)~sum;
    if (result == 0) result = 0xffff;
    packet[ihl + 6] = (uint8_t)(result >> 8);
    packet[ihl + 7] = (uint8_t)result;
}

static void recalc_tcp_checksum(uint8_t *packet, size_t ip_length) {
    size_t ihl = (packet[0] & 0x0f) * 4;
    if (ihl < 20 || ip_length < ihl + 20 || packet[9] != 6) return;
    size_t tcp_length = ip_length - ihl;
    packet[ihl + 16] = packet[ihl + 17] = 0;
    uint32_t sum = 0;
    auto add_words = [&sum](const uint8_t *data, size_t length) {
        while (length > 1) {
            sum += ((uint16_t)data[0] << 8) | data[1];
            data += 2;
            length -= 2;
        }
        if (length) sum += (uint16_t)data[0] << 8;
    };
    add_words(packet + 12, 8); // IPv4 source + destination
    sum += 6;                  // zero byte + protocol number
    sum += (uint16_t)tcp_length;
    add_words(packet + ihl, tcp_length);
    while (sum >> 16) sum = (sum & 0xffff) + (sum >> 16);
    uint16_t result = (uint16_t)~sum;
    packet[ihl + 16] = (uint8_t)(result >> 8);
    packet[ihl + 17] = (uint8_t)result;
}

static NatTcpFlow *find_tcp_flow(const uint8_t *client_ip, const uint8_t *server_ip,
                                 uint16_t client_port, uint16_t server_port) {
    uint32_t now = to_ms_since_boot(get_absolute_time());
    for (auto &flow : nat_tcp_flows) {
        if (tcp_flow_expired(flow, now)) flow.active = false;
        if (flow.active && flow.client_port == client_port &&
            flow.server_port == server_port &&
            memcmp(flow.client_ip, client_ip, 4) == 0 &&
            memcmp(flow.server_ip, server_ip, 4) == 0) return &flow;
    }
    return nullptr;
}

static NatTcpFlow *find_tcp_reverse_flow(const uint8_t *server_ip,
                                         uint16_t client_port,
                                         uint16_t server_port) {
    uint32_t now = to_ms_since_boot(get_absolute_time());
    for (auto &flow : nat_tcp_flows) {
        if (tcp_flow_expired(flow, now)) flow.active = false;
        if (flow.active && flow.client_port == client_port &&
            flow.server_port == server_port &&
            memcmp(flow.server_ip, server_ip, 4) == 0) return &flow;
    }
    return nullptr;
}

// Reuse a closed TCP flow immediately for a new SYN. Still-active flows are
// never evicted, so an ongoing transfer remains protected.
static NatTcpFlow *allocate_tcp_flow(uint32_t now) {
    NatTcpFlow *oldest_closed = nullptr;
    for (auto &candidate : nat_tcp_flows) {
        if (tcp_flow_expired(candidate, now)) {
            candidate.active = false;
            return &candidate;
        }
        if (candidate.closed_at &&
            (!oldest_closed || candidate.closed_at < oldest_closed->closed_at)) {
            oldest_closed = &candidate;
        }
    }
    return oldest_closed;
}

static err_t ethernet_output_trace(struct netif *netif, struct pbuf *p,
                               const ip4_addr_t *ipaddr) {
    mark_network_activity();
    if (ipaddr) {
        printf("W5500 TX to %u.%u.%u.%u (%u bytes)\n",
               ip4_addr1(ipaddr), ip4_addr2(ipaddr),
               ip4_addr3(ipaddr), ip4_addr4(ipaddr),
               (unsigned)p->tot_len);
    }
    err_t result = original_ethernet_output(netif, p, ipaddr);
    printf("W5500 output result: %d (up=%d link=%d)\n",
           (int)result, netif_is_up(netif) ? 1 : 0,
           netif_is_link_up(netif) ? 1 : 0);
    if (w5500_lwip_take_tx_timeout()) {
        printf("W5500 TX stalled: automatic restart scheduled.\n");
        watchdog_reboot(0, 0, 100);
    }
    return result;
}

static err_t network_output_ip_packet(struct netif *netif, struct pbuf *packet,
                                      const ip4_addr_t *destination) {
    ip4_addr_t next_hop = *destination;
    if (!ip4_addr_netcmp(destination, &netif->ip_addr, &netif->netmask))
        next_hop = netif->gw;
    return netif->output(netif, packet, &next_hop);
}

static err_t ethernet_input_trace(struct pbuf *p, struct netif *netif) {
    mark_network_activity();
    printf("W5500 input frame: %u bytes\n", p ? (unsigned)p->tot_len : 0u);
    constexpr size_t ETH_HEADER_LEN = 14;
    if (p && p->tot_len >= ETH_HEADER_LEN + 20) {
        uint8_t header[60] = {};
        size_t available_ip_bytes = p->tot_len - ETH_HEADER_LEN;
        size_t header_bytes = available_ip_bytes < sizeof(header) ?
                              available_ip_bytes : sizeof(header);
        pbuf_copy_partial(p, header, header_bytes, ETH_HEADER_LEN);
        if ((header[0] >> 4) == 4) {
            size_t ihl = (header[0] & 0x0f) * 4;
            printf("W5500 RX IPv4 %u.%u.%u.%u -> %u.%u.%u.%u (%u bytes)\n",
                   header[12], header[13], header[14], header[15],
                   header[16], header[17], header[18], header[19],
                   (unsigned)p->tot_len);

            // Return TCP segments to an Atari flow registered by an outbound SYN.
            if (header[9] == 6 && ihl >= 20 &&
                p->tot_len >= ETH_HEADER_LEN + ihl + 20 &&
                header[16] == ip4_addr1(&netif->ip_addr) &&
                header[17] == ip4_addr2(&netif->ip_addr) &&
                header[18] == ip4_addr3(&netif->ip_addr) &&
                header[19] == ip4_addr4(&netif->ip_addr)) {
                uint8_t tcp_head[20];
                pbuf_copy_partial(p, tcp_head, sizeof(tcp_head), ETH_HEADER_LEN + ihl);
                uint16_t source_port = ((uint16_t)tcp_head[0] << 8) | tcp_head[1];
                uint16_t destination_port = ((uint16_t)tcp_head[2] << 8) | tcp_head[3];
                NatTcpFlow *flow = find_tcp_reverse_flow(header + 12,
                                                         destination_port, source_port);
                if (flow) {
                    uint8_t reply[SLIP_MAX_FRAME];
                    size_t ip_length = ((size_t)header[2] << 8) | header[3];
                    if (ip_length <= sizeof(reply) &&
                        ip_length <= p->tot_len - ETH_HEADER_LEN) {
                        pbuf_copy_partial(p, reply, ip_length, ETH_HEADER_LEN);
                        memcpy(reply + 16, flow->client_ip, 4);
                        reply[10] = reply[11] = 0;
                        uint16_t ip_sum = checksum16(reply, ihl);
                        reply[10] = (uint8_t)(ip_sum >> 8);
                        reply[11] = (uint8_t)ip_sum;
                        recalc_tcp_checksum(reply, ip_length);
                        slip_send_frame(reply, ip_length);
                        update_tcp_flow(flow, tcp_head[13], false,
                                        to_ms_since_boot(get_absolute_time()));
                        printf("NAT TCP reply -> Atari (%u bytes, %u -> %u)\n",
                               (unsigned)ip_length, source_port, destination_port);
                        pbuf_free(p);
                        return ERR_OK;
                    }
                }
            }

            // Minimal ICMP NAT: restore a reply to the Atari SLIP client.
            if (header[9] == 1 && ihl >= 20 && ihl + 8 <= sizeof(header)) {
                printf("ICMP RX type=%u id=%04X seq=%04X nat=%d\n",
                       header[ihl],
                       ((unsigned)header[ihl + 4] << 8) | header[ihl + 5],
                       ((unsigned)header[ihl + 6] << 8) | header[ihl + 7],
                       nat_icmp_active ? 1 : 0);
            }
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
int main() {
    stdio_init_all();
    init_status_leds();
    sleep_ms(2000); // USB CDC monitor enumeration.
    printf("NetworkBox W5500 / SLIP boot\n");

    // UART RS-232 side: GP0 TX, GP1 RX, 19200 8N1.
    uart_init(UART_ID, BAUD_RATE);
    gpio_set_function(UART_TX_PIN, GPIO_FUNC_UART);
    gpio_set_function(UART_RX_PIN, GPIO_FUNC_UART);
    irq_set_exclusive_handler(UART0_IRQ, uart_rx_irq_handler);
    irq_set_enabled(UART0_IRQ, true);
    uart_set_irq_enables(UART_ID, true, false);

    // W5500 SPI0 wiring already used by the Network Box:
    // MISO GP16, CS GP17, SCK GP18, MOSI GP19, RESET GP20.
    printf("Initialising W5500 on SPI0...\n");
    wizchip_spi_initialize();
    wizchip_cris_initialize();
    wizchip_reset();
    wizchip_initialize();
    wizchip_check();
    setSHAR(mac);
    printf("W5500 chip ready, version=%u\n", getVERSIONR());
    uint8_t phy_status = PHY_LINK_OFF;
    while (phy_status == PHY_LINK_OFF) {
        ctlwizchip(CW_GET_PHYLINK, &phy_status);
        if (phy_status == PHY_LINK_OFF) {
            printf("W5500: waiting for Ethernet link (check RJ45 cable)\n");
            sleep_ms(1000);
        }
    }
    printf("W5500 Ethernet link up\n");

    int8_t socket_result = socket(0, Sn_MR_MACRAW, 0, 0);
    if (socket_result < 0) {
        printf("W5500 MACRAW socket failed: %d\n", (int)socket_result);
        return 1;
    }
    printf("W5500 MACRAW socket ready\n");

    lwip_init();
    netif_add(&ethernet_netif, IP4_ADDR_ANY, IP4_ADDR_ANY, IP4_ADDR_ANY,
              nullptr, netif_initialize, netif_input);
    ethernet_netif.name[0] = 'e';
    ethernet_netif.name[1] = '0';
    netif_set_link_callback(&ethernet_netif, netif_link_callback);
    original_ethernet_output = ethernet_netif.output;
    ethernet_netif.output = ethernet_output_trace;
    original_ethernet_input = ethernet_netif.input;
    ethernet_netif.input = ethernet_input_trace;
    netif_set_default(&ethernet_netif);
    netif_set_link_up(&ethernet_netif);
    netif_set_up(&ethernet_netif);
    err_t dhcp_result = dhcp_start(&ethernet_netif);
    printf("W5500 DHCP start: %d\n", (int)dhcp_result);

    ip4_addr_t slip_ip, slip_mask, slip_gw;
    IP4_ADDR(&slip_ip, 192, 168, 7, 1);
    IP4_ADDR(&slip_mask, 255, 255, 255, 0);
    IP4_ADDR(&slip_gw, 0, 0, 0, 0);
    netif_add(&slip_netif, &slip_ip, &slip_mask, &slip_gw,
              nullptr, slip_netif_init, ip_input);
    netif_set_up(&slip_netif);
    netif_set_link_up(&slip_netif);
    printf("lwIP SLIP interface ready: 192.168.7.1\n");

    uint32_t reported_uart_overflow = 0;
    bool dhcp_reported = false;
    watchdog_enable(5000, true);
    watchdog_update();
    printf("NetworkBox watchdog enabled (5 s).\n");
    while (true) {
        watchdog_update();
        // Drain Ethernet frames from W5500 socket 0 into lwIP.
        uint16_t available = 0;
        getsockopt(0, SO_RECVBUF, &available);
        if (available > 0) {
            int32_t frame_length = recv_lwip(0, ethernet_rx_frame,
                                             sizeof(ethernet_rx_frame));
            if (frame_length > 0 && frame_length <= (int32_t)sizeof(ethernet_rx_frame)) {
                struct pbuf *frame = pbuf_alloc(PBUF_RAW, (u16_t)frame_length, PBUF_POOL);
                if (frame) {
                    pbuf_take(frame, ethernet_rx_frame, (u16_t)frame_length);
                    err_t input_result = ethernet_netif.input(frame, &ethernet_netif);
                    if (input_result != ERR_OK) pbuf_free(frame);
                } else {
                    printf("W5500 RX: lwIP pbuf allocation failed\n");
                }
            }
        }

        // Process Atari SLIP bytes; UART RX interrupt keeps buffering meanwhile.
        while (uart_rx_tail != uart_rx_head) {
            uint32_t tail = uart_rx_tail;
            uint8_t byte = uart_rx_ring[tail];
            __dmb();
            uart_rx_tail = (tail + 1) & UART_RX_RING_MASK;
            slip_receive_byte(byte);
        }

        sys_check_timeouts(); // DHCP, ARP, TCP and UDP timers.
        uint32_t overflow = uart_rx_overflow;
        if (overflow != reported_uart_overflow) {
            printf("UART RX ring overflow: %u bytes dropped total\n", overflow);
            reported_uart_overflow = overflow;
        }
        uint32_t now = to_ms_since_boot(get_absolute_time());
        update_status_leds(now);
        if (!dhcp_reported && !ip4_addr_isany_val(ethernet_netif.ip_addr)) {
            printf("NetworkBox active - W5500 IP %s\n",
                   ip4addr_ntoa(&ethernet_netif.ip_addr));
            dhcp_reported = true;
        }
        tight_loop_contents();
    }
}

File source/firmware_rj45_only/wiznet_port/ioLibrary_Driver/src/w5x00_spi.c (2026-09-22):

/**
 * Copyright (c) 2022 WIZnet Co.,Ltd
 *
 * SPDX-License-Identifier: BSD-3-Clause
 */

/**
 * ----------------------------------------------------------------------------------------------------
 * Includes
 * ----------------------------------------------------------------------------------------------------
 */
#include <stdio.h>

#include "port_common.h"

#include "wizchip_conf.h"
#include "w5x00_spi.h"
#include "board_list.h"

#if (DEVICE_BOARD_NAME == W55RP20_EVB_PICO)
#include "wiznet_spi_pio.h"
#endif


/**
 * ----------------------------------------------------------------------------------------------------
 * Variables
 * ----------------------------------------------------------------------------------------------------
 */
static critical_section_t g_wizchip_cri_sec;

#ifdef USE_SPI_DMA
static uint dma_tx;
static uint dma_rx;
static dma_channel_config dma_channel_config_tx;
static dma_channel_config dma_channel_config_rx;
#endif


#ifdef USE_SPI_PIO
wiznet_spi_config_t g_spi_config = {
    .data_in_pin = PIN_MISO,
    .data_out_pin = PIN_MOSI,
    .cs_pin = PIN_CS,
    .clock_pin = PIN_SCK,
    .irq_pin = PIN_IRQ,
    .reset_pin = PIN_RST,
    .clock_div_major = 2,
    .clock_div_minor = 0,
};

wiznet_spi_handle_t spi_handle;
#endif

/**
 * ----------------------------------------------------------------------------------------------------
 * Functions
 * ----------------------------------------------------------------------------------------------------
 */
static inline void wizchip_select(void)
{
    gpio_put(PIN_CS, 0);
}

static inline void wizchip_deselect(void)
{
    gpio_put(PIN_CS, 1);
}

void wizchip_reset()
{
    gpio_init(PIN_RST);

#ifdef USE_SPI_PIO
    gpio_pull_up(PIN_RST);
    gpio_set_dir(PIN_RST, GPIO_OUT);
    sleep_ms(5);
#else
    gpio_set_dir(PIN_RST, GPIO_OUT);
#endif

    gpio_put(PIN_RST, 0);
    sleep_ms(100);

    gpio_put(PIN_RST, 1);
    sleep_ms(100);

    bi_decl(bi_1pin_with_name(PIN_RST, "W5x00 RESET"));
}

#ifndef USE_SPI_PIO
static uint8_t wizchip_read(void)
{
    uint8_t rx_data = 0;
    uint8_t tx_data = 0xFF;

    spi_read_blocking(SPI_PORT, tx_data, &rx_data, 1);

    return rx_data;
}

static void wizchip_write(uint8_t tx_data)
{
    spi_write_blocking(SPI_PORT, &tx_data, 1);
}

#ifdef USE_SPI_DMA
static void wizchip_read_burst(uint8_t *pBuf, uint16_t len)
{
    uint8_t dummy_data = 0xFF;

    channel_config_set_read_increment(&dma_channel_config_tx, false);
    channel_config_set_write_increment(&dma_channel_config_tx, false);
    dma_channel_configure(dma_tx, &dma_channel_config_tx,
                          &spi_get_hw(SPI_PORT)->dr, // write address
                          &dummy_data,               // read address
                          len,                       // element count (each element is of size transfer_data_size)
                          false);                    // don't start yet

    channel_config_set_read_increment(&dma_channel_config_rx, false);
    channel_config_set_write_increment(&dma_channel_config_rx, true);
    dma_channel_configure(dma_rx, &dma_channel_config_rx,
                          pBuf,                      // write address
                          &spi_get_hw(SPI_PORT)->dr, // read address
                          len,                       // element count (each element is of size transfer_data_size)
                          false);                    // don't start yet

    dma_start_channel_mask((1u << dma_tx) | (1u << dma_rx));
    dma_channel_wait_for_finish_blocking(dma_rx);
}

static void wizchip_write_burst(uint8_t *pBuf, uint16_t len)
{
    uint8_t dummy_data;

    channel_config_set_read_increment(&dma_channel_config_tx, true);
    channel_config_set_write_increment(&dma_channel_config_tx, false);
    dma_channel_configure(dma_tx, &dma_channel_config_tx,
                          &spi_get_hw(SPI_PORT)->dr, // write address
                          pBuf,                      // read address
                          len,                       // element count (each element is of size transfer_data_size)
                          false);                    // don't start yet

    channel_config_set_read_increment(&dma_channel_config_rx, false);
    channel_config_set_write_increment(&dma_channel_config_rx, false);
    dma_channel_configure(dma_rx, &dma_channel_config_rx,
                          &dummy_data,               // write address
                          &spi_get_hw(SPI_PORT)->dr, // read address
                          len,                       // element count (each element is of size transfer_data_size)
                          false);                    // don't start yet

    dma_start_channel_mask((1u << dma_tx) | (1u << dma_rx));
    dma_channel_wait_for_finish_blocking(dma_rx);
}
#endif
#endif

static void wizchip_critical_section_lock(void)
{
    critical_section_enter_blocking(&g_wizchip_cri_sec);
}

static void wizchip_critical_section_unlock(void)
{
    critical_section_exit(&g_wizchip_cri_sec);
}

void wizchip_spi_initialize(void)
{
#ifdef USE_SPI_PIO
    spi_handle = wiznet_spi_pio_open(&g_spi_config);
    (*spi_handle)->set_active(spi_handle);

#else
    // this example will use SPI0 at 5MHz
    spi_init(SPI_PORT, 5000 * 1000);

    gpio_set_function(PIN_SCK, GPIO_FUNC_SPI);
    gpio_set_function(PIN_MOSI, GPIO_FUNC_SPI);
    gpio_set_function(PIN_MISO, GPIO_FUNC_SPI);

    // make the SPI pins available to picotool
    bi_decl(bi_3pins_with_func(PIN_MISO, PIN_MOSI, PIN_SCK, GPIO_FUNC_SPI));

    // chip select is active-low, so we'll initialise it to a driven-high state
    gpio_init(PIN_CS);
    gpio_set_dir(PIN_CS, GPIO_OUT);
    gpio_put(PIN_CS, 1);

    // make the SPI pins available to picotool
    bi_decl(bi_1pin_with_name(PIN_CS, "W5x00 CHIP SELECT"));

#ifdef USE_SPI_DMA
    dma_tx = dma_claim_unused_channel(true);
    dma_rx = dma_claim_unused_channel(true);

    dma_channel_config_tx = dma_channel_get_default_config(dma_tx);
    channel_config_set_transfer_data_size(&dma_channel_config_tx, DMA_SIZE_8);
    channel_config_set_dreq(&dma_channel_config_tx, DREQ_SPI0_TX);

    // We set the inbound DMA to transfer from the SPI receive FIFO to a memory buffer paced by the SPI RX FIFO DREQ
    // We coinfigure the read address to remain unchanged for each element, but the write
    // address to increment (so data is written throughout the buffer)
    dma_channel_config_rx = dma_channel_get_default_config(dma_rx);
    channel_config_set_transfer_data_size(&dma_channel_config_rx, DMA_SIZE_8);
    channel_config_set_dreq(&dma_channel_config_rx, DREQ_SPI0_RX);
    channel_config_set_read_increment(&dma_channel_config_rx, false);
    channel_config_set_write_increment(&dma_channel_config_rx, true);
#endif
#endif
}

void wizchip_cris_initialize(void)
{
    critical_section_init(&g_wizchip_cri_sec);
    reg_wizchip_cris_cbfunc(wizchip_critical_section_lock, wizchip_critical_section_unlock);
}
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

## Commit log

2026-09-22 Add case assembly photos and Pico placement guide
2026-09-24 Clarify Pico retaining rail assembly
